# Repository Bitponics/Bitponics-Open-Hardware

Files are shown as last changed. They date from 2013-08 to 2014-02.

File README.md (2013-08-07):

### Hardware
- Bitponics board
- [FTDI adapter](http://www.amazon.com/FTDI-Basic-Breakout-5V/dp/B0068QKQEA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)
- Mini USB cable

### Software
- [Arduino 1.0.1](http://arduino.cc/en/Main/Software)
- [FTDI driver](http://www.ftdichip.com/Drivers/VCP.htm)

### Setup
- Copy all directories from `./libraries` into your Arduino's global `libraries` folder. (Usually ~/Documents/Arduino/libraries)
- Open Bitponics code in Arduino
- Set board to "Arduino 2560"
- Set serial your usb serial port
- upload firmware

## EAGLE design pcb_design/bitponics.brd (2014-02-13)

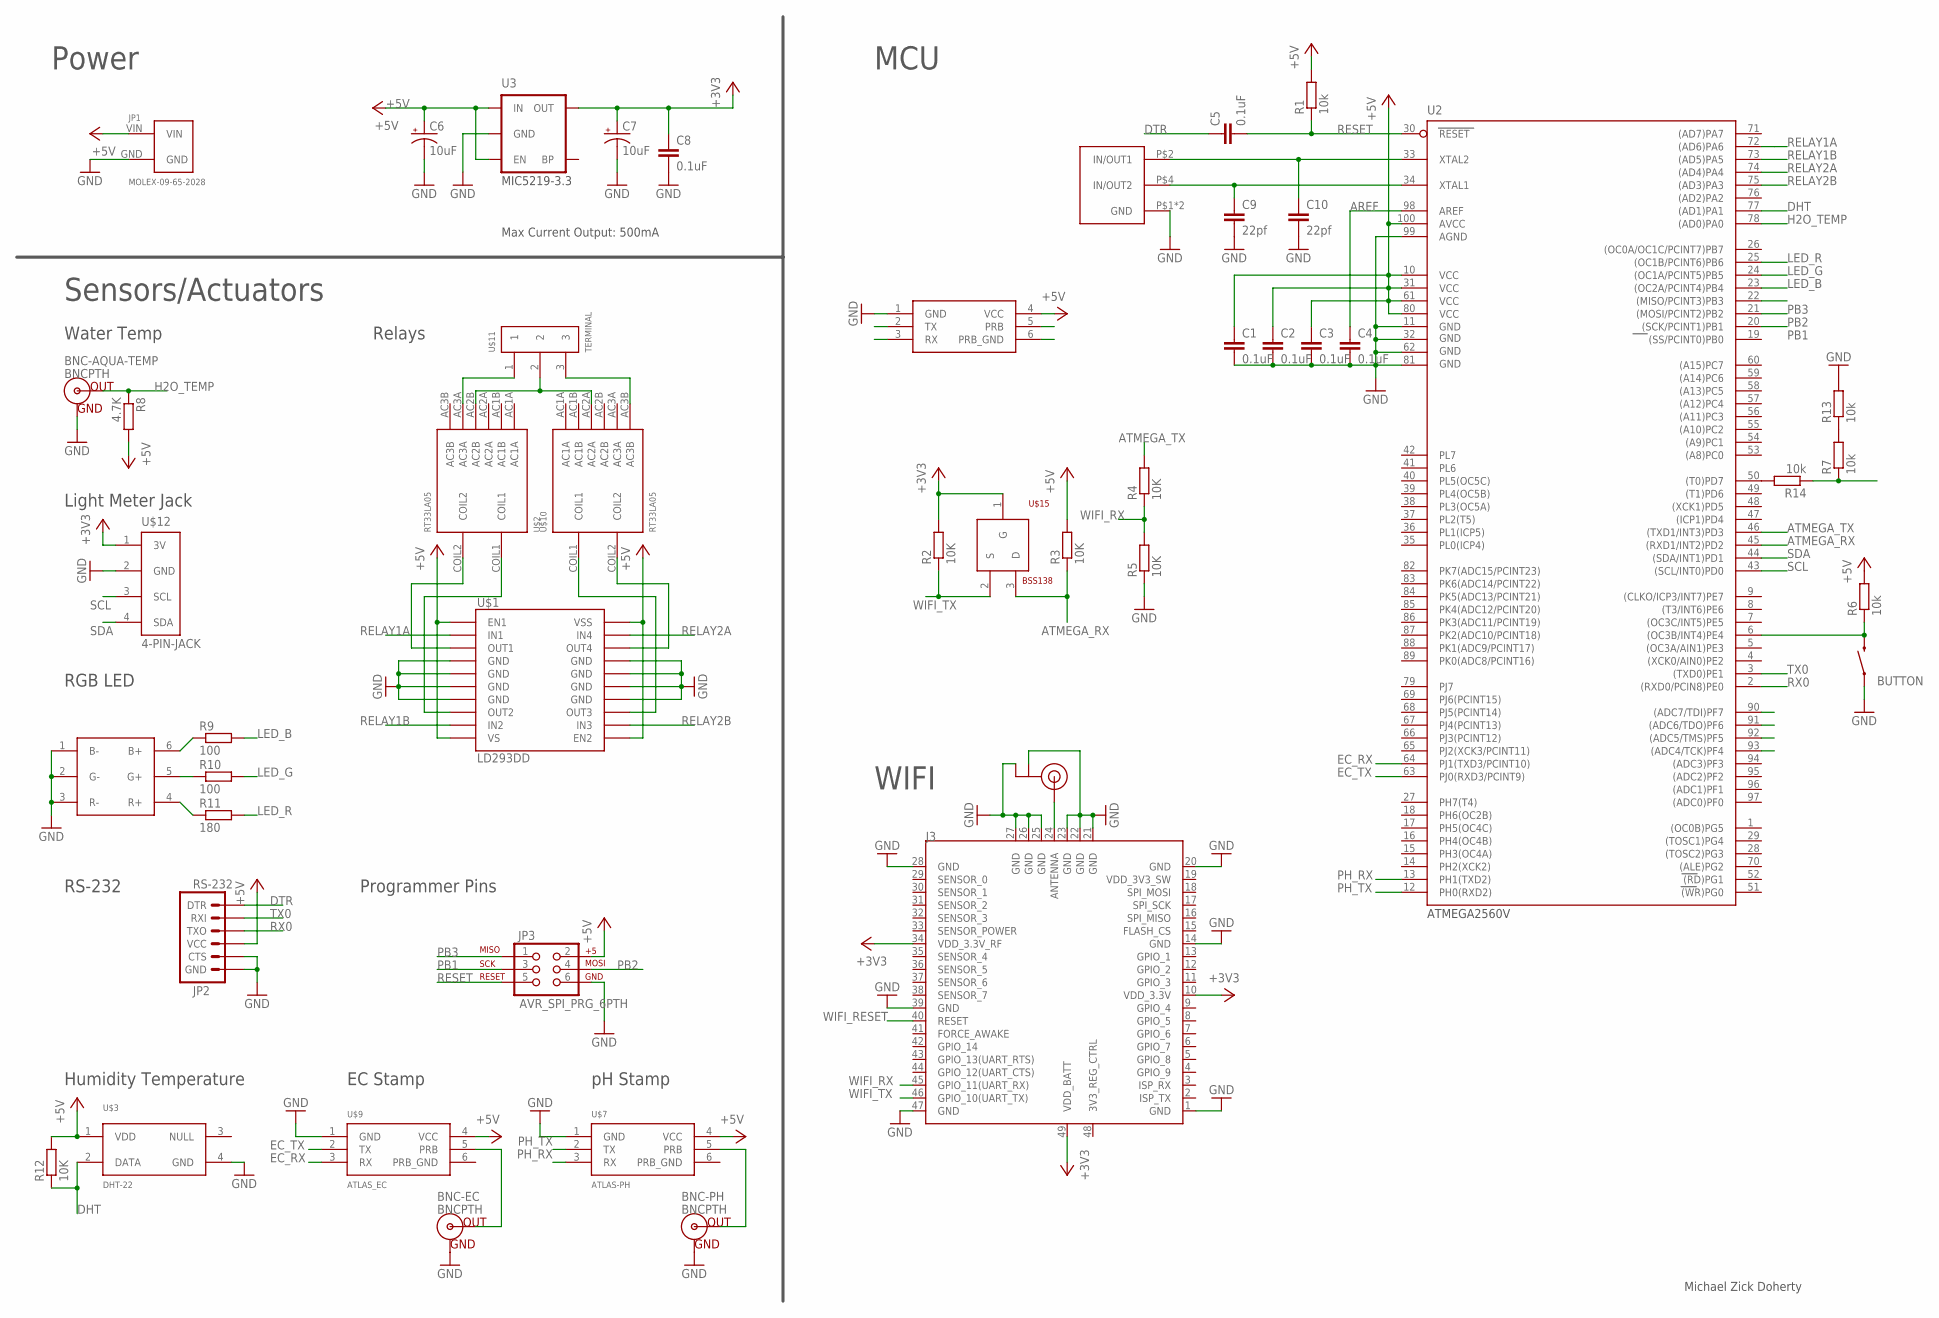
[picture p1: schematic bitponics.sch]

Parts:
BNC-AQUA-TEMP: BNCPTH; BNC
BNC-EC: BNCPTH; BNC
BNC-PH: BNCPTH; BNC
BUTTON: FSMRA2JH
C1, C2, C3, C4, C5, C8: 0.1uF; C0603
C6, C7: 10uF; EIA3216
C9, C10: 22pf; C0603
J3: WIFI-RN-171; 49P-1.27-26.67X17.78
JP1: MOLEX-09-65-2028; 09-65-2028
JP2: RS-232; 1X06_LOCK
JP3: AVR_SPI_PRG_6PTH; 2X3
R1, R6, R7, R13, R14: 10k; R0603
R2, R3, R4, R5, R12: 10K; R0603
R8: 4.7K; R0603
R9, R10: 100; R0603
R11: 180; R0603
U2: ATMEGA2560AU; TQFP100
U3: V_REG_LDOSMD; SOT23-5
U13: RGB-LED
U$1: LD293DD; SO-20LD
U$2, U$10: RT33LA05
U$3: DHT-22; DHT22
U$4, U$7: ATLAS-PH; PH
U$5: U.FL
U$6: ECX-32
U$9: ATLAS_EC; EC
U$11: TERMINAL
U$12: 4-PIN-JACK
U$15: BSS138; SOT23

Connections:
+3V3: C7.A (+), C8.1, J3.10 (VDD_3.3V), J3.34 (VDD_3.3V_RF), J3.49 (VDD_BATT), R2.2, U3.5 (OUT), U$12.1 (3V), U$15.1 (G)
+5V: C1.1, C2.1, C3.1, C6.A (+), JP1.VIN, JP2.4 (VCC), JP3.2, R1.2, R3.2, R6.2, R8.2, R12.2, U2.10 (VCC), U2.31 (VCC1), U2.61 (VCC2), U2.80 (VCC3), U2.100 (AVCC), U3.1 (IN), U3.3 (EN), U$1.1 (EN1), U$1.10 (VS), U$1.11 (EN2), U$1.20 (VSS), U$3.1 (VDD), U$4.4 (VCC), U$7.4 (VCC), U$9.4 (VCC)
A4: U2.93 ((ADC4/TCK)PF4), U$4.5 (PRB)
A5: U2.92 ((ADC5/TMS)PF5), U$4.6 (PRB_GND)
A6: U2.91 ((ADC6/TDO)PF6), U$4.3 (RX)
A7: U2.90 ((ADC7/TDI)PF7), U$4.2 (TX)
AREF: C4.1, U2.98 (AREF)
ATMEGA_RX: R3.1, U2.45 ((RXD1/INT2)PD2), U$15.3 (D)
ATMEGA_TX: R4.2, U2.46 ((TXD1/INT3)PD3)
DHT: R12.1, U2.77 ((AD1)PA1), U$3.2 (DATA)
DTR: C5.1, JP2.1 (DTR)
EC_RX: U2.64 (PJ1(TXD3/PCINT10)), U$9.3 (RX)
EC_TX: U2.63 (PJ0(RXD3/PCINT9)), U$9.2 (TX)
GND: BNC-AQUA-TEMP.GND, BNC-EC.GND, BNC-PH.GND, BUTTON.2A (1), C1.2, C2.2, C3.2, C4.2, C6.C (-), C7.C (-), C8.2, C9.2, C10.2, J3.1 (GND), J3.14 (GND), J3.20 (GND), J3.21 (GND), J3.22 (GND), J3.23 (GND), J3.25 (GND), J3.26 (GND), J3.27 (GND), J3.28 (GND), J3.39 (GND), J3.47 (GND), JP1.GND, JP2.5 (CTS), JP2.6 (GND), JP3.6, R5.1, R13.2, U2.11 (GND), U2.32 (GND1), U2.62 (GND2), U2.81 (GND3), U2.99 (AGND), U3.2 (GND), U13.1 (B-), U13.2 (G-), U13.3 (R-), U$1.4 (GND), U$1.5 (GND), U$1.6 (GND), U$1.7 (GND), U$1.14 (GND), U$1.15 (GND), U$1.16 (GND), U$1.17 (GND), U$3.4 (GND), U$4.1 (GND), U$5.P$1 (GND), U$5.P$2 (GND), U$6.P$1 (GND), U$6.P$3 (GND), U$7.1 (GND), U$9.1 (GND), U$12.2 (GND)
H2O_TEMP: BNC-AQUA-TEMP.S (OUT), R8.1, U2.78 ((AD0)PA0)
LED_B: R9.2, U2.23 ((OC2A/PCINT4)PB4)
LED_G: R10.2, U2.24 ((OC1A/PCINT5)PB5)
LED_R: R11.2, U2.25 ((OC1B/PCINT6)PB6)
unnamed: BNC-EC.S (OUT), U$9.5 (PRB)
unnamed: BNC-PH.S (OUT), U$7.5 (PRB)
unnamed: U$1.13 (OUT3), U$10.COIL1
unnamed: U$2.AC3A, U$11.1
unnamed: U$2.AC2B, U$10.AC2A, U$11.2
unnamed: U$10.AC3B, U$11.3
unnamed: C10.1, U2.33 (XTAL2), U$6.P$2 (IN/OUT1)
unnamed: U$1.18 (OUT4), U$10.COIL2
unnamed: R10.1, U13.5 (G+)
unnamed: R11.1, U13.4 (R+)
unnamed: R9.1, U13.6 (B+)
unnamed: C9.1, U2.34 (XTAL1), U$6.P$4 (IN/OUT2)
unnamed: J3.24 (ANTENNA), U$5.P$3 (SIGNAL)
unnamed: U$1.3 (OUT1), U$2.COIL2
unnamed: U$1.8 (OUT2), U$2.COIL1
unnamed: R7.2, R13.1
unnamed: R14.2, U2.50 ((T0)PD7)
unnamed: BUTTON.2B (2), R6.1, U2.6 ((OC3B/INT4)PE4)
PB1: JP3.3, U2.20 ((SCK/PCINT1)PB1)
PB2: JP3.4, U2.21 ((MOSI/PCINT2)PB2)
PB3: JP3.1, U2.22 ((MISO/PCINT3)PB3)
PH_RX: U2.13 (PH1(TXD2)), U$7.3 (RX)
PH_TX: U2.12 (PH0(RXD2)), U$7.2 (TX)
RELAY1A: U2.72 ((AD6)PA6), U$1.2 (IN1)
RELAY1B: U2.73 ((AD5)PA5), U$1.9 (IN2)
RELAY2A: U2.74 ((AD4)PA4), U$1.19 (IN4)
RELAY2B: U2.75 ((AD3)PA3), U$1.12 (IN3)
RESET: C5.2, JP3.5, R1.1, U2.30 (RESET)
RX0: JP2.3 (TXO), U2.2 ((RXD0/PCIN8)PE0)
SCL: U2.43 ((SCL/INT0)PD0), U$12.3 (SCL)
SDA: U2.44 ((SDA/INT1)PD1), U$12.4 (SDA)
TX0: JP2.2 (RXI), U2.3 ((TXD0)PE1)
WIFI_RESET: J3.40 (RESET), R7.1, R14.1
WIFI_RX: J3.45 (GPIO_11(UART_RX)), R4.1, R5.2
WIFI_TX: J3.46 (GPIO_10(UART_TX)), R2.1, U$15.2 (S)

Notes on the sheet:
Sensors/Actuators
Power
MCU
MIC5219-3.3
ATMEGA2560V
Max Current Output: 500mA
Michael Zick Doherty
Programmer Pins
RS-232
Water Temp
RGB LED
Humidity Temperature
EC Stamp
pH Stamp
WIFI
Relays
Light Meter Jack

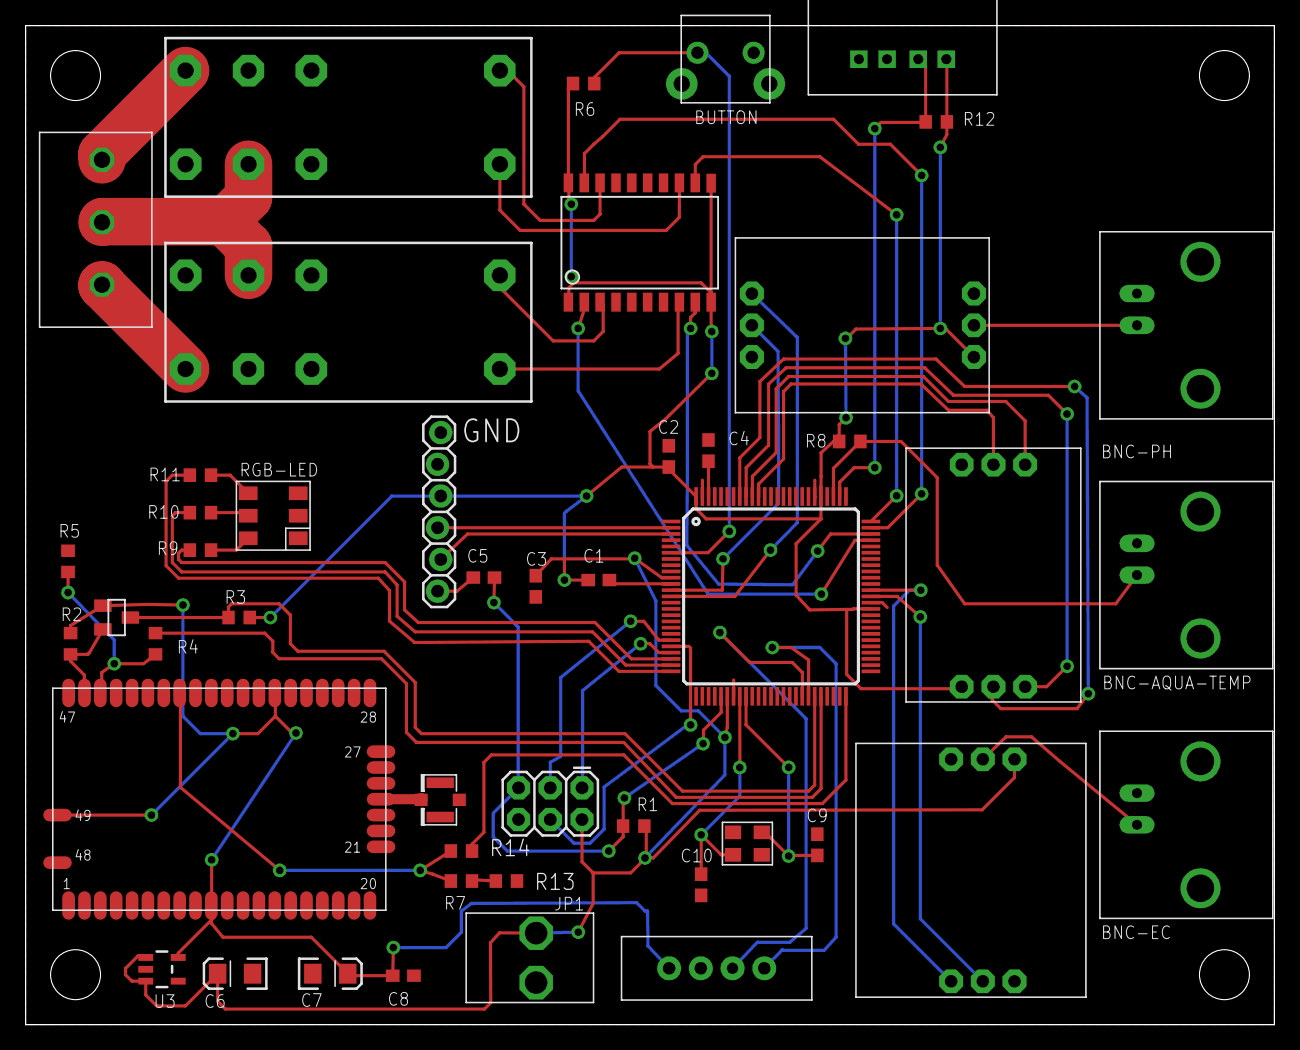
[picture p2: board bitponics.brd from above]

Board: 2 copper layers, 100.0 x 80.0 mm, 47 parts (0 on the bottom side), 53 nets.

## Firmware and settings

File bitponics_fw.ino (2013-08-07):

//global includes
#include <Wire.h>
//#include "customDataTypes.h"
#include <avr/wdt.h>

const byte RED[] = {
  255, 0,0};
const byte YELLOW[] = {
  255, 255,0};
const byte ORANGE[] = {
  255,124,0};
const byte BLUE[] = {
  0,0,255};
const byte GREEN[] = {
  0,255,0};
const byte PURPLE[] = {
  255,0,255};


#define RESET 7
#define WIFI_RESET 38
#define BUTTON A2

char addr[16];
char buf[80];
long timeout;
unsigned long reset_time = 1200000; //20 minutes for reset
unsigned long requestCount = 0;
int terminalMode;

int errors = 0;
int errMax = 5;
boolean setupSequence = true;
boolean debug = false;

unsigned int completedPosts = 0;
unsigned int failedPosts = 0;

//*********************  Sensor Variables  ************************ **************
char ec[5];
char lux[6];
char air[7];
char water[7];
char hum[7];
char ph[6];
char wl[6];
//********************************************************************************

void setup() {
  setupLED();
  setupWDT();

  digitalWrite(WIFI_RESET, HIGH);
  digitalWrite(RESET, HIGH);
  pinMode(RESET, OUTPUT);
  pinMode(BUTTON, INPUT);

  setupRelays();

  Serial.begin(115200);
  Serial.println();
  Serial.println(F("**********************"));
  Serial.println(F("-> Device Boot"));
}

void loop(){

  if(setupSequence && !terminalMode){
    setupSensors(38400);
    if(!digitalRead(BUTTON)) checkTerm();
    if(!terminalMode){
      setupWifi(9600);
      setupSequence = false;
    }
  }

  checkBtn();
  if(!terminalMode) wifiLoop();
  if(millis()>reset_time) resetBoard();
}

void checkTerm(){
  Serial.println(F("Mode Switch"));
  int pressCount = 0;
  int startTime = millis();
  boolean lastState;
  while(startTime+3000>millis()){
    boolean curState = digitalRead(BUTTON);
    if(lastState!=curState){
      pressCount++; 
      Serial.println(pressCount);
    }
    if (pressCount>4){
      Serial.println(F("term mode"));
      terminalMode = true;
      break;
    }
    lastState = curState;
  }
  Serial.println(F("end mode switch"));

}

void setupSensors(unsigned int DATABAUD){
  Serial.println(F("-> Initalizing sensors"));
  setupTemps(); // TODO: change to setupTempAndHumidity();
  setupLight();
  setupEc(DATABAUD);
  setupPh(DATABAUD);
}

//
//void terminal(){
//
//  while(Serial1.available() > 0) {
//    Serial.write(Serial1.read());
//  }
//
//  if(Serial.available()) {
//    Serial1.write(Serial.read());
//  }
//
//}

void resetBoard(){
  //wdt_enable(WDTO_8S); 
  Serial.println(F("-> Board reset"));
  resetWifi();
  wdt_enable(WDTO_30MS); 
  delay(1000);
}

void setupWDT() {
  cli();
  MCUSR = 0;
  WDTCSR |= B00011000;
  WDTCSR = B01000111;
  sei();
}

//void serialEvent(){
//  Serial.println(".");
//  if(!terminalMode){
//    Serial.readBytesUntil('\r', buf, 5);
//    //    if(buf == "exit"){
//    //      terminalMode = false; 
//    //    }
//    Serial.print(F("buffer: "));
//    Serial.println(buf);
//    if(buf == "$$$"){
//      terminalMode = 1;
//      Serial.println(F("attempting wifi terminal"));
//      Serial1.print(F("$$$")); 
//    }
//    if(buf == "sen"){
//      terminalMode = 2;
//      Serial.print(F("Sensor mode")); 
//    }
//  }
//  else if(terminalMode==1){ 
//    Serial1.write(Serial.read());
//  }
//  else{
//    char inbyte = Serial.read();
//    Serial.println(F("sensor cmd"));
//  }
//}
//
//void serialEvent1(){
//  if(terminalMode  == 1){
//    Serial.write(Serial1.read());
//  }
//
//}

ISR(WDT_vect){
  //Serial.println(F("~~~"));
  if(millis()-timeout > 45000 && requestCount > 0){

    resetBoard(); 
  }
}

//void logMsg(int type, String msg){
//  switch(type){
//    case SENSOR:
//    Serial.print("-");
//    Serial.println(msg);
//    break;
//  }
//  
//  
//}


//String tempChar(float t, char* buf){
//  char* c = dtostrf(t,5,2,buf);
//  return c;
//}

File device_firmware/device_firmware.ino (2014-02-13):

float ver = 1.02;

//global includes
#include <Wire.h>
//#include "customDataTypes.h"
#include <avr/wdt.h>

const byte RED[] = {
  255, 0,0};
const byte YELLOW[] = {
  255, 255,0};
const byte ORANGE[] = {
  255,124,0};
const byte BLUE[] = {
  0,0,255};
const byte GREEN[] = {
  0,255,0};
const byte PURPLE[] = {
  255,0,255};
const byte BLACK[] = {
  0,0,0};
  
#define RESET 7
#define WIFI_RESET 38
#define BUTTON A2
#define PING_RX_PIN A6
#define PING_TX_PIN A5



char addr[16];
//char buf[80];
long timeout;
unsigned long reset_time = 600000; //10 minutes for reset
unsigned long requestCount = 0;

int errors = 0;
int errMax = 5;
boolean setupSequence = true;
boolean debug = true;

unsigned int completedPosts = 0;
unsigned int failedPosts = 0;

void setupWifi(unsigned int BAUD);
void wifiApRequestHandler();
boolean wifiConnection();
void wifiLoop();
void sendInitialJSON();



//*********************  Sensor Variables  ***************************************
char ec[5];
char lux[6];
char air[7];
char water[7];
char hum[7];
char ph[6];
char wl[6];
//********************************************************************************

void setup() {
  setupLED();
  setupWDT();


  pinMode(RESET, OUTPUT);
  pinMode(BUTTON, INPUT);
  pinMode(PING_RX_PIN, INPUT);
  pinMode(PING_TX_PIN, OUTPUT);
  digitalWrite(PING_TX_PIN, LOW);
  digitalWrite(WIFI_RESET, HIGH);
  digitalWrite(RESET, HIGH);

  setupRelays();

  Serial.begin(115200);
  Serial.println();
  Serial.println(F("**********************"));
  Serial.print(F("-> Device Boot v"));
  Serial.println(ver);

  setupSensors(38400);
  setupWifi(9600);
}

void loop(){
  wifiLoop();
  //if(millis()>reset_time) resetBoard();
}


void setupSensors(unsigned int DATABAUD){
  Serial.println(F("-> Initializing sensors"));
  setupTemps(); // TODO: change to setupTempAndHumidity();
  setupLight();
  setupEc(DATABAUD);
  setupPh(DATABAUD);
}


void resetBoard(){
  //wdt_enable(WDTO_8S); 
  Serial.println(F("-> Board reset"));
  resetWifi();
  wdt_enable(WDTO_30MS); 
  delay(1000);
}

void setupWDT() {
  cli();
  MCUSR = 0;
  WDTCSR |= B00011000;
  WDTCSR = B01000111;
  sei();
}


ISR(WDT_vect){
  if(millis()-timeout > 45000 && requestCount > 0){
    resetBoard(); 
  }
}

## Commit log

2012-09-20 Typo Fix & Adding Wifi Connection
    [wifi.ino]
2012-09-21 Added Ec,PH & Json Call to sensor_logs
2012-09-21 poll sensor_logs & refresh_status
2012-09-22 Added EEPROM read and write reset
    [wifi.ino, wifiRequestHandlers.ino]
2013-02-13 changed lib references to reference the local versions & rolled back my wifi logic refactoring from a couple commits ago
2013-03-20 Fixed AP connection, AP Request Headers fixed GET & POST checking
    [wifiRequestHandlers.ino, wifiRoutines.ino]
2013-03-25 Keeping Current
2013-03-25 copying all of Chris P's libraries into the repo, renaming lib to libraries to be more consistent with Arduino environment
2013-03-31 LED function, WDT reset function, new lux library
    [led.ino, light.ino, wifiRoutines.ino]
2013-05-14 new device protocol
2013-05-15 streamline calibration flow
2013-05-26 updated relay triggering
2013-09-26 Fix for reset button
    [wifi.ino, wifiRequestHandlers.ino, wifiRoutines.ino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]
2013-10-07 Fix calibration flow, updated for latest version of Arduino IDE
    [calib.ino, wifi.ino, wifiRequestHandlers.ino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]
2013-12-03 -updated wifi association flow
2014-01-10 implemented reset circuit
2014-01-16 fixed bug with wifi scan, optimized calibration
    [calib.ino, led.ino, wifi.ino]
2014-02-05 updated timings on calibration
2014-02-12 adding pcb design files + reorganizing
    [bitponics.brd, bitponics.sch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]

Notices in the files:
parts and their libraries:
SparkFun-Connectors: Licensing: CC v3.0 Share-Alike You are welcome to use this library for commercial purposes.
